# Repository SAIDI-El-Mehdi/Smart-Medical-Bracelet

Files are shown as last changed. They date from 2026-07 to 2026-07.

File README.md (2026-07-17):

# Smart Medical Bracelet (IoT Health Monitor) 🩺⌚

An integrated mechatronics and IoT project focused on designing a wearable medical bracelet for continuous health monitoring. This project encompasses the full product development lifecycle, from system modeling to hardware design and mobile application deployment.

<p align="center">
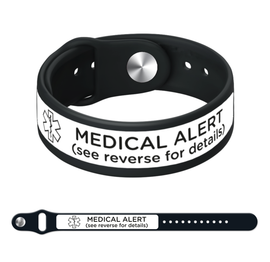
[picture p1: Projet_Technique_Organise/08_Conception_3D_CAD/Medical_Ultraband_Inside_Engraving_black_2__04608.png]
Smart Medical Bracelet Render
  
</p>

---

## 🚀 Key Engineering Dimensions

*   **Systems Engineering (SysML):** Comprehensive system architecture modeling (Requirements, Block Definition, and State Machine diagrams) to define functional relationships and data flow.
*   **Hardware Architecture (PCB Design - Eagle):** Custom printed circuit board design integrating vital sign sensors, power management, and wireless communication modules (IoT/Bluetooth).
*   **Mechanical & CAD Design (3D CAD):** Ergonomic and durable wearable casing designed for comfort, optimal sensor placement against the skin, and manufacturability.
*   **Software & Connectivity (Mobile App):** A dedicated companion mobile application developed to receive, process, and display real-time telemetry data from the bracelet.

---

## 📂 Repository Structure

The project is highly organized into the following engineering phases:

```text
Projet_Technique_Organise/
├── 01_Rapport/                  # Comprehensive project documentation and thesis reports
├── 02_Presentation/             # Slide decks and technical defense materials
├── 03_Code_Source/              # Firmware for the embedded microcontroller
├── 04_Simulation/               # System and physical simulations
├── 05_PCB_Eagle/                # PCB schematics and board layouts (Autodesk Eagle)
├── 06_Documentation/            # Datasheets and component references
├── 08_Conception_3D_CAD/        # Mechanical enclosure models and CAD assemblies
├── 09_Modelisation_SysML/       # System modeling diagrams (MBSE)
└── 10_Application_Mobile/       # Source code for the companion mobile application

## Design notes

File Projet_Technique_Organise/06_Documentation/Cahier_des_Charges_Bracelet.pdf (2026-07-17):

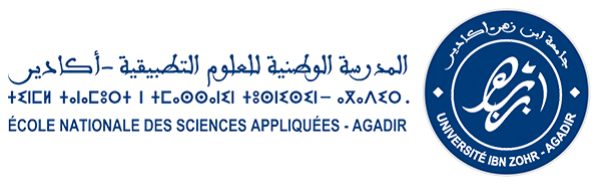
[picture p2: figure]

## École Nationale des Sciences Appliquées d’Agadir

### Université Ibn Zohr

### Filière : Mécatronique et technologies automobiles

### Module : Projet Technique

# Cahier des charges

# Bracelet de surveillance du rythme cardiaque et détection de chute

Membres du groupe

Hamid El-Ghardaouy
Hajar Ziki
Wael El Garrab

Encadrants

Pr. O. Outamsaa
Pr. R. Latif
Pr. M. Bouasrya

### Année universitaire 2025–2026

Cahier des charges – Bracelet de surveillance | ENSA Agadir

## Résumé

Ce cahier des charges définit les besoins, les fonctions, les contraintes, les exigences techniques et les critères de validation du projet de bracelet de surveillance du rythme cardiaque et de détection de chute. Le système visé est un prototype académique portable destiné à représenter ou acquérir une information cardiaque, exploiter des données de mouvement, détecter une situation anormale et déclencher une alerte locale.

Le bracelet repose sur une architecture mécatronique associant un boîtier mécanique, une carte électronique d’interconnexion, un microcontrôleur ESP32-C3 Super Mini, un capteur cardiaque MAX30102, un capteur inertiel MPU6050, un buzzer, un bouton d’acquittement, un interrupteur marche/arrêt et une alimentation par batterie. La logique embarquée est étudiée par simulation afin de vérifier la lecture des données, la comparaison avec des seuils expérimentaux, la détection d’anomalie et l’activation de l’alerte. Une application mobile prototype complète l’étude en affichant des valeurs simulées, des alertes, des courbes, un historique et un contact d’urgence.

Le projet ne constitue pas un dispositif médical certifié. Il est défini comme une base technique d’étude, de simulation, d’intégration et de validation progressive. Les essais matériels réels, l’ajustement expérimental des seuils, la validation des capteurs physiques, l’autonomie, la robustesse mécanique et la communication réelle avec l’application mobile restent des étapes à finaliser avant toute conclusion sur le fonctionnement réel du bracelet.

Page 1 sur 22

## Table des matières

1 Introduction | 5
2 Présentation générale du projet | 5
3 Problématique | 6
4 Objectifs du projet | 7
5 Analyse du besoin | 8
6 Fonctions principales | 9
7 Fonctions contraintes | 10
8 Architecture fonctionnelle et technique | 11

Page 2 sur 22

9 Exigences techniques générales | 12
10 Exigences mécaniques | 13
11 Exigences électroniques | 14
12 Exigences embarquées | 15
13 Application mobile prototype | 17

Page 3 sur 22

14 Analyse de risque et apprentissage automatique | 18
15 Contraintes de sécurité | 18
16 Critères de validation | 18
17 Limites du projet | 19
18 Livrables attendus | 20
19 Planning prévisionnel | 21
20 Conclusion | 22

Page 4 sur 22

## 1 Introduction

Les systèmes embarqués portables occupent une place importante dans les applications modernes de surveillance, d’assistance et de suivi en temps réel. Un bracelet intelligent présente un intérêt particulier, car il est proche du corps, accessible, léger et adapté à une utilisation quotidienne. Cette proximité permet de placer un capteur cardiaque contre la peau et de suivre le mouvement du porteur à l’aide d’une unité inertielle.

Le problème étudié concerne la surveillance locale d’un utilisateur à partir de deux infor-mations complémentaires : une information physiologique liée au rythme cardiaque et une information dynamique liée à l’accélération et au mouvement du corps. Une variation anormale du rythme cardiaque ou une chute peut nécessiter une alerte rapide, au minimum sous forme sonore, puis éventuellement sous forme de notification ou de message préparé dans une application mobile.

La motivation du projet est de concevoir une chaîne mécatronique complète : intégration mécanique, conception électronique, routage PCB, acquisition de données, traitement embarqué, alerte locale et préparation d’une extension mobile. Le présent cahier des charges fixe le cadre technique du projet afin de guider la conception, limiter les ambiguïtés entre les sous-systèmes et préparer une validation progressive.

## 2 Présentation générale du projet

### 2.1 Idée générale

Le projet consiste à concevoir un bracelet portable de surveillance capable de remplir trois fonctions essentielles : surveiller une information liée au rythme cardiaque, détecter une chute ou un impact à partir d’un capteur inertiel et déclencher une alerte en cas d’anomalie. Le système doit rester compact, compréhensible, modifiable et compatible avec un travail académique de conception, de simulation et de validation progressive.

### 2.2 Rôle de la partie mécanique

La partie mécanique assure l’intégration physique du bracelet. Elle comprend le boîtier, le couvercle, les ouvertures fonctionnelles, les supports internes, les zones d’accès utilisateur et les réservations destinées au PCB, à la batterie, aux capteurs et aux actionneurs. Elle doit protéger les composants, permettre le port au poignet, faciliter le montage et éviter les contraintes excessives sur les éléments sensibles, notamment la batterie et les fils.

Page 5 sur 22

### 2.3 Rôle de la partie électronique

La partie électronique organise les liaisons entre le microcontrôleur, les capteurs, l’alimentation et les éléments d’alerte. Le PCB étudié joue principalement le rôle d’une carte d’interconnexion centrée sur l’ESP32-C3 Super Mini. Les modules externes, notamment le MAX30102, le MPU6050, le buzzer, le bouton, l’interrupteur et l’entrée d’alimentation, sont raccordés par connecteurs et fils afin de faciliter leur positionnement dans le boîtier.

### 2.4 Rôle du système embarqué

Le système embarqué réalise l’initialisation, l’acquisition, le traitement et la décision. Il doit lire l’information cardiaque disponible, lire les données d’accélération, calculer des critères simples de chute ou d’impact, comparer les valeurs à des seuils expérimentaux, activer le buzzer lorsque l’alarme est active et permettre un acquittement par bouton.

### 2.5 Rôle de la simulation et de l’application mobile

La simulation sous Wokwi sert à vérifier la logique de fonctionnement avant l’intégration physique. Dans la version étudiée, l’information cardiaque peut être représentée par une entrée analogique simulée, tandis que le MPU6050, le buzzer et le bouton permettent de tester la logique d’alerte. L’application mobile prototype permet de visualiser des valeurs simulées, de conserver un historique, de préparer un message d’urgence et de poser les bases d’une future connexion réelle.

### 2.6 Fonctionnement global attendu

Le fonctionnement attendu peut être résumé par la chaîne suivante :

### Capteurs → Microcontrôleur → Traitement embarqué → Alerte → Interface utilisateur

Au démarrage, le bracelet est alimenté par batterie, initialise le microcontrôleur et configure les entrées, sorties et communications. En fonctionnement normal, il surveille les valeurs disponibles. Si un rythme cardiaque anormal, une chute libre ou un impact est détecté, l’alerte est activée. L’utilisateur peut ensuite acquitter l’alerte selon la logique prévue.

## 3 Problématique

La problématique du projet est formulée ainsi :

Page 6 sur 22

Comment concevoir un système portable de surveillance capable d’intégrer des capteurs, une carte électronique, une logique embarquée et une interface d’alerte, tout en respectant
les contraintes d’un projet académique de conception mécatronique ?

Cette problématique impose une approche pluridisciplinaire. Le système doit être suffisamment compact pour être porté au poignet, suffisamment clair pour être câblé et testé, suffisamment sécurisé pour éviter les erreurs de tension et suffisamment évolutif pour intégrer une validation matérielle et une future communication mobile.

## 4 Objectifs du projet

### 4.1 Objectif principal

L’objectif principal est de concevoir un prototype académique de bracelet portable capable de surveiller une information cardiaque, d’analyser le mouvement du porteur et de déclencher une alerte locale lorsqu’une situation anormale est détectée, tout en servant de base à une validation matérielle future.

### 4.2 Objectifs secondaires

Les objectifs secondaires sont les suivants :

— concevoir un boîtier mécanique portable intégrant les composants principaux ;

— réaliser une étude électronique autour de l’ESP32-C3 Super Mini;

— concevoir un PCB d’interconnexion adapté aux modules câblés ;

— prévoir la surveillance du rythme cardiaque avec le MAX30102 ou une représentation simulée pendant la phase Wokwi ;

— exploiter les données du MPU6050 pour étudier la détection de chute ;

— avertir l’utilisateur par une alerte sonore locale ;

— prévoir un acquittement simple par bouton poussoir ;

— respecter les niveaux d’alimentation, la masse commune et la compatibilité logique 3,3 V ;

— vérifier la logique de fonctionnement par simulation embarquée ;

— préparer une application mobile prototype pour l’affichage, l’historique et le contact d’urgence ;

Page 7 sur 22

— identifier clairement les limites avant la validation sur prototype réel.

## 5 Analyse du besoin

### 5.1 Utilisateur cible

L’utilisateur cible est une personne portant un bracelet de surveillance dans un contexte expérimental, pédagogique ou académique. Le système peut servir à illustrer une solution d’assistance locale, de suivi simple et d’alerte, sans remplacer un suivi médical réel.

### 5.2 Contexte d’utilisation

Le bracelet est destiné à être porté au poignet dans un environnement d’étude, de démonstration ou de test. L’utilisation prévue concerne principalement la validation du principe de fonctionnement : acquisition ou représentation des mesures, traitement et alerte. Les conditions réelles d’usage prolongé, de transpiration, de mouvement complexe, de choc mécanique ou d’autonomie complète doivent encore être évaluées sur prototype physique.

### 5.3 Besoin principal

Le besoin principal est de disposer d’un objet portable académique capable de surveiller une information liée au rythme cardiaque, d’exploiter les données d’un capteur inertiel pour détecter une chute, de déclencher une alerte locale et de préparer une extension mobile. Le système doit rester une base d’étude et de validation progressive, sans prétendre constituer un dispositif médical certifié.

### 5.4 Besoins secondaires

Les besoins secondaires concernent l’ergonomie, la maintenance, l’accès aux composants, la clarté du câblage, la stabilité mécanique des capteurs, la sécurité électrique, l’évolutivité du code embarqué, la documentation des résultats et la préparation d’essais réels futurs.

### 5.5 Contraintes d’usage

Le bracelet doit être compact, léger, non agressif pour le poignet et simple à manipuler. Les éléments accessibles, comme le bouton et l’interrupteur, doivent être positionnés de manière à éviter les appuis accidentels tout en restant utilisables. Le capteur cardiaque

Page 8 sur 22 doit être orienté vers la peau et le buzzer doit disposer d’une sortie sonore suffisante pour rendre l’alerte identifiable dans un contexte de démonstration.

### 5.6 Limites du prototype

Le prototype actuel reste une étude académique. Les données de simulation ne représentent pas toutes les conditions réelles. Le comportement du capteur cardiaque dépendra du contact avec la peau, de la lumière parasite, du mouvement et du placement mécanique. La détection de chute dépendra de la fixation du MPU6050, des seuils choisis et du scénario réel de chute.

## 6 Fonctions principales

Table 1: Fonctions principales du bracelet.

Code Fonction | Description | Critère attendu Priorité Validation
FP1 | Surveiller une
information cardiaque | Acquérir ou représenter une valeur de BPM dans le cadre du prototype. | Valeur BPM disponible, réelle ou simulée.
Élevée | Simulation
| | puis test MAX30102 réel.
FP2 | Détecter une chute Exploiter les accélérations
| du MPU6050 pour détecter une chute libre, un impact ou un mouvement anormal. | État de chute
| | ou d’impact identifié.
Élevée | Wokwi puis
| | scénarios réels.
FP3 | Déclencher une
alerte locale

Activer un buzzer
lorsqu’une anomalie
cardiaque ou une chute est détectée.

Buzzer actif
pendant
l’alarme.

Élevée Simulation
puis test
matériel.

FP4 Permettre
l’acquittement

Permettre à l’utilisateur
d’arrêter ou de confirmer
l’alerte par bouton.

Changement
d’état reconnu
par le
programme.

Élevée Simulation
puis test du
bouton.

FP5 Afficher ou
préparer les
données

Préparer l’affichage des
valeurs, alertes, courbes, historique et contact dans une application prototype.

Interface
mobile lisible
avec données
simulées.

Moyenne Test logiciel de
l’application.

FP6 Intégrer les
composants

Placer le PCB, les capteurs, la batterie, le buzzer, le bouton et l’interrupteur
dans un boîtier portable.

Composants
positionnés
sans conflit
après
adaptation.

Élevée Étude CAO
puis
assemblage
réel.

Page 9 sur 22

## 7 Fonctions contraintes

Table 2: Fonctions contraintes du projet.

Code Contrainte | Description | Priorité | Vérification
FC1 | Portabilité | Le système doit conserver un
| encombrement compatible avec un port au poignet. | Élevée | Étude CAO.
FC2 | Confort au poignet Les arêtes doivent être adoucies et
la zone en contact avec la peau ne doit pas être agressive.

Élevée Revue CAO
puis essai réel.

FC3 Sécurité électrique Les rails doivent être clairement identifiés et les GPIO protégés contre une tension incorrecte.

Élevée ERC, DRC,
inspection.
FC4 | Compatibilité des tensions | Le 5 V ne doit jamais être appliqué directement aux GPIO de l’ESP32-C3.
Élevée | Contrôle des
nets.
FC5 | Alimentation par batterie | L’alimentation doit être compatible avec les modules et la masse commune.
Élevée | Mesures
futures.
FC6 | Intégration du PCB La carte doit être compatible avec le
| | boîtier ou le boîtier doit être adapté.
Élevée | Comparaison
CAO/PCB.
FC7 | Position du capteur cardiaque | Le MAX30102 doit être orienté vers la peau et aligné avec son ouverture.
Élevée | Vue CAO puis
essai réel.
FC8 | Fixation du capteur inertiel | Le MPU6050 doit être fixé de manière stable.
Élevée | Contrôle
mécanique
futur.
FC9 | Masse commune | Tous les blocs doivent partager une référence GND commune.
Élevée | Inspection
schéma/PCB.
FC10 Accessibilité du
| bouton | Le bouton doit être accessible sans appui involontaire.
Moyenne | Vue CAO puis
essai
utilisateur.
FC11 Accessibilité de
| l’interrupteur | L’interrupteur marche/arrêt doit être manipulable.
Moyenne | Vue CAO puis
essai réel.
FC12 Sortie sonore du
| buzzer | Le boîtier doit permettre la sortie du son.
Moyenne | Ouverture
CAO puis test
sonore.
FC13 Limites de
| simulation | Les résultats simulés ne doivent pas être assimilés à des tests réels.
Élevée | Mention dans
le rapport.
FC14 Coût raisonnable | Les composants doivent rester
| | compatibles avec un projet académique.
Moyenne | Choix de
modules
courants.

Page 10 sur 22

Code Contrainte | Description | Priorité | Vérification
FC15 Simplicité de réalisation | Le système doit rester compréhensible, câblable et modifiable. | Élevée | Revue
| | | d’architecture.

## 8 Architecture fonctionnelle et technique

### 8.1 Architecture globale

L’architecture du bracelet suit une chaîne de traitement simple et modulaire :

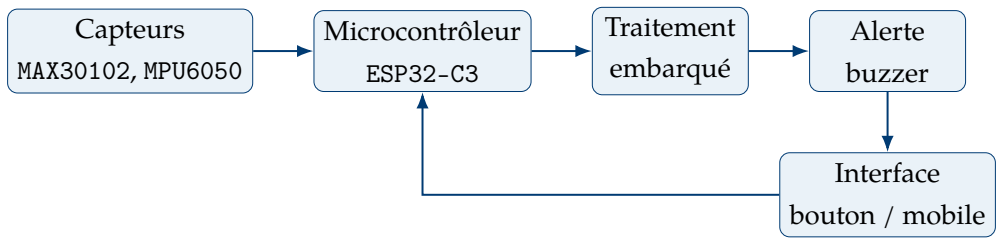
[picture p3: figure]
Capteurs; MAX30102, MPU6050; Microcontrôleur; ESP32-C3; Traitement embarqué; Alerte; buzzer; Interface; bouton / mobile

### 8.2 Blocs du système

— Boîtier mécanique : supporte, protège et positionne les composants.

— Microcontrôleur : l’ESP32-C3 Super Mini assure l’acquisition, le traitement et la commande.

— Capteur cardiaque : le MAX30102 est prévu pour fournir une information liée au rythme cardiaque lors d’une validation matérielle.

— Capteur inertiel : le MPU6050 fournit les accélérations utilisées pour la détection de chute.

— Alerte locale : le buzzer informe l’utilisateur lorsqu’une alarme est active.

— Interface utilisateur : le bouton permet l’acquittement ou le test ; l’interrupteur contrôle l’alimentation.

— Alimentation : batterie Li-Po et entrée d’alimentation prévues, avec masse commune et niveaux compatibles.

— Application mobile prototype : affiche les valeurs simulées, les alertes, l’historique, les courbes et le contact d’urgence.

Page 11 sur 22

### 8.3 Flux principaux

— Flux d’information : capteurs vers microcontrôleur, puis microcontrôleur vers sortie d’alerte et application prototype.

— Flux d’énergie : batterie ou entrée d’alimentation vers microcontrôleur, capteurs et buzzer.

— Flux de commande : décision embarquée vers buzzer, puis acquittement par bouton vers microcontrôleur.

## 9 Exigences techniques générales

Table 3: Exigences techniques principales.

Code Exigence | Justification | Critère de validation

État

ET1 Utiliser un ESP32-C3 Super Mini.
Format compact,
traitement embarqué et
évolution connectée.

Présence dans le
schéma et
initialisation du
programme.

Étudié

ET2 Prévoir le capteur MAX30102.

Surveillance cardiaque
future.

Lecture réelle à
valider ; BPM
simulé en Wokwi.

Partiel

ET3 | Utiliser le capteur MPU6050. | Détection de chute à partir des accélérations.
Reconnaissance I2C
et lecture des axes.

Simulé

ET4 | Identifier SDA et SCL. | Communication I2C entre capteurs et microcontrôleur.
Continuité des
lignes et masse
commune.

Étudié

ET5 Commander un buzzer. Alerte locale simple et visible dans le comportement du système.

Activation lorsque
l’alarme est active.

Simulé

ET6 Prévoir un bouton d’acquittement.

Interaction utilisateur
simple.

Changement d’état
détecté par le
programme.

Simulé

ET7 Prévoir une alimentation par batterie et entrée dédiée.

Fonctionnement portable
et tests futurs.

Tension correcte et
polarité vérifiée.

À valider

ET8 Garantir les niveaux 3,3 V sur les GPIO.

Protection de l’ESP32-C3. Aucun 5 V direct sur GPIO.

À vérifier

Page 12 sur 22

Code Exigence | Justification | Critère de validation

État

ET9 Concevoir un PCB d’interconnexion.

Faciliter le câblage et
l’intégration.

ERC, DRC et
inspection des
connecteurs.

Étudié

ET10 Vérifier les dimensions PCB/support.

Éviter les conflits
mécaniques.

Comparaison PCB
42,85 × 38,09 mm
et support 36,50 ×
29,50 mm.

À ajuster

ET11 Simuler la logique sous Wokwi.

Valider le fonctionnement
avant prototype réel.

Cas d’alerte
visibles au
moniteur série et
au Serial Plotter.

Réalisé

ET12 Préparer une application mobile prototype.

Visualisation et extension connectée future.

Écrans, historique,
notifications et
contact testés avec
données simulées.

Prototype

ET13 Limiter l’interprétation médicale.

Éviter toute conclusion
abusive.

Mention claire
dans le cahier des
charges et le
rapport.

Respecté

## 10 Exigences mécaniques

### 10.1 Forme du boîtier

Le boîtier doit adopter une forme compacte, arrondie et compatible avec un port au poignet. Les arêtes agressives doivent être évitées. Le couvercle doit permettre l’accès interne pour les tests, la maintenance et les ajustements.

### 10.2 Intégration du PCB

Le PCB doit être maintenu dans le boîtier sans contact dangereux avec la batterie ou les fils. L’étude actuelle montre une différence entre les dimensions du PCB et celles du support interne prévu. Cette différence impose soit un redimensionnement du support, soit une adaptation de la carte avant fabrication.

Page 13 sur 22

### 10.3 Position du capteur cardiaque

Le MAX30102 doit être placé de manière à aligner sa zone optique avec une ouverture orientée vers la peau. L’ouverture doit rester dégagée afin de ne pas masquer la zone active du capteur.

### 10.4 Position du capteur inertiel

Le MPU6050 doit être fixé de façon stable pour limiter les vibrations parasites. Son placement doit éviter les mouvements relatifs entre le module et le boîtier, car ces mouvements peuvent perturber la détection de chute.

### 10.5 Bouton, interrupteur et buzzer

Le bouton poussoir doit être accessible sans risque d’appui involontaire. L’interrupteur marche/arrêt doit être placé sur une zone manipulable. Le buzzer doit disposer d’une ouverture ou d’une zone de sortie sonore afin que l’alerte reste audible.

### 10.6 Protection et assemblage

Le boîtier doit protéger les modules contre les contacts directs, les contraintes mécaniques et les courts-circuits. La batterie Li-Po doit être maintenue sans compression excessive. Les fils doivent passer dans des zones dégagées, sans pincement par le couvercle.

## 11 Exigences électroniques

### 11.1 Microcontrôleur

L’ESP32-C3 Super Mini est l’unité centrale du système. Il assure l’acquisition des données, le traitement logique, l’activation de l’alerte et la préparation d’une future communication avec l’application mobile.

### 11.2 Capteurs

Le MAX30102 est prévu pour assurer la fonction de surveillance cardiaque lors d’une validation matérielle. Le MPU6050 assure la mesure inertielle pour l’étude de la détection de chute. Les deux modules doivent être raccordés avec des lignes SDA, SCL, VCC et GND clairement identifiées.

Page 14 sur 22

### 11.3 Alimentation

Le système doit disposer d’une alimentation adaptée au microcontrôleur et aux modules. La masse commune est obligatoire. La présence d’un rail 5 V doit être traitée avec prudence : il peut servir d’entrée d’alimentation selon l’architecture retenue, mais il ne doit jamais être appliqué directement aux GPIO de l’ESP32-C3.

### 11.4 Entrées et sorties

Le buzzer doit être raccordé à une sortie compatible avec le courant admissible. Si le buzzer exige un courant supérieur à la capacité d’une broche GPIO, un étage de commande devra être ajouté dans une version améliorée. Le bouton poussoir doit disposer d’un état logique stable, par résistance de tirage interne ou externe. La LED prévue dans le schéma électronique peut servir d’indicateur visuel, mais elle n’est pas considérée comme validée dans la simulation actuelle si elle n’est pas commandée par le programme.

### 11.5 Règles de câblage et de routage

Les règles de câblage importantes sont les suivantes :

— identifier clairement les rails 3V3, 5V et GND;

— éviter toute connexion directe du 5V sur les GPIO ;

— garder une masse commune entre tous les modules ;

— contrôler les lignes SDA et SCL;

— vérifier les connecteurs avant fabrication ;

— exécuter l’ERC pour vérifier la cohérence du schéma ;

— exécuter le DRC pour vérifier les règles géométriques du routage ;

— contrôler les largeurs de pistes d’alimentation ;

— vérifier la continuité du bouton, du buzzer, de la LED et de l’interrupteur.

## 12 Exigences embarquées

Page 15 sur 22

### 12.1 Initialisation du système

Le programme doit initialiser la communication série, configurer les broches d’entrée et de sortie, initialiser le bus I2C et vérifier la présence du MPU6050. L’alarme doit être inactive au démarrage.

### 12.2 Acquisition des données

Le système doit acquérir une information liée au rythme cardiaque et lire les accélérations selon les axes du MPU6050. Dans la simulation Wokwi actuelle, le rythme cardiaque est représenté par une entrée analogique convertie en BPM.

### 12.3 Traitement des mesures

Le traitement doit calculer une grandeur exploitable à partir des accélérations, notamment la norme d’accélération. Les seuils de rythme cardiaque et d’accélération sont des paramètres de simulation et doivent être ajustés après essais réels.

### 12.4 Détection d’anomalie cardiaque

Une anomalie cardiaque est détectée si le BPM sort de la plage définie par les seuils bas et haut. Les seuils utilisés dans la version prototype servent à vérifier la logique et ne constituent pas une recommandation médicale.

### 12.5 Détection de chute

La détection de chute repose sur deux cas simples : une accélération inférieure à un seuil de chute libre ou une accélération supérieure à un seuil d’impact. Cette logique doit être validée expérimentalement, car les conditions réelles dépendent du mouvement, de la fixation du capteur et du port du bracelet.

### 12.6 Activation et acquittement de l’alerte

L’alerte est activée lorsqu’une anomalie cardiaque ou une chute est détectée. Le buzzer est activé tant que l’alarme reste active. Le bouton poussoir doit permettre l’acquittement de l’alerte selon la logique prévue.

Page 16 sur 22

### 12.7 Validation par simulation

La simulation doit permettre d’observer les variables principales : BPM, accélération, présence du MPU6050, anomalie cardiaque, chute, acquittement et état de l’alarme. Les résultats obtenus en simulation ne remplacent pas les tests sur prototype réel.

## 13 Application mobile prototype

### 13.1 Objectif de l’application

L’application mobile constitue une extension prototype du bracelet. Elle ne reçoit pas encore de données réelles du bracelet dans la version actuelle. Elle permet de valider l’interface, l’affichage, l’historique, les alertes et le contact d’urgence à partir de données simulées.

### 13.2 Fonctions attendues

L’application mobile prototype doit permettre :

— l’affichage du BPM simulé ;

— l’affichage de l’état de chute ou de mouvement anormal ;

— l’affichage d’un état général : normal, danger ou déconnecté ;

— la conservation d’un historique d’alertes ;

— l’affichage de courbes simples ;

— l’enregistrement d’un contact d’urgence ;

— la préparation d’un message SOS contrôlé par l’utilisateur;

— la préparation d’une future communication BLE avec l’ESP32-C3.

### 13.3 Limites de l’application

L’application ne remplace pas un système médical ni un service d’urgence certifié. Les données affichées sont simulées dans la version actuelle. La communication BLE, la réception de données réelles, la gestion robuste du stockage et les tests prolongés restent des évolutions futures.

Page 17 sur 22

## 14 Analyse de risque et apprentissage automatique

Une analyse de risque avancée ou une approche par apprentissage automatique peut être envisagée comme perspective. Elle ne fait pas partie de la validation actuelle du bracelet. Une telle évolution nécessiterait :

— une collecte de données réelles ;

— un étiquetage fiable des scénarios ;

— un nettoyage des données ;

— une extraction de caractéristiques pertinentes ;

— un entraînement du modèle ;

— une validation sur des données séparées ;

— une analyse des fausses alertes et des non-détections.

Sans base de données suffisante et sans validation expérimentale rigoureuse, aucun modèle ne peut garantir une prédiction fiable ni une interprétation médicale.

## 15 Contraintes de sécurité

— éviter les tensions incorrectes sur les broches du microcontrôleur ;

— éviter les courts-circuits entre l’alimentation et la masse ;

— isoler correctement les parties conductrices du contact utilisateur ;

— maintenir la batterie sans compression, perforation ou échauffement anormal ;

— vérifier la polarité de l’alimentation avant toute mise sous tension ;

— éviter les fausses alertes autant que possible par un réglage progressif des seuils ;

— distinguer clairement les résultats simulés des résultats expérimentaux réels ;

— préciser que le système n’est pas un dispositif médical certifié.

## 16 Critères de validation

Page 18 sur 22

Table 4: Critères de validation du prototype académique.

Critère | Méthode de vérification | Résultat attendu | État
Validation mécanique | Revue CAO, comparaison des volumes, contrôle des ouvertures et supports. | Boîtier cohérent avec les composants prévus. | Réalisée au niveau CAO
Intégration PCB/boîtier | Comparaison dimensions PCB, support interne et zones de câblage. | Adaptation identifiée avant fabrication. | À ajuster

Alimentation
correcte

Mesure future des rails et contrôle de polarité.

Tensions compatibles avec
l’ESP32-C3 et les modules.

À valider
matériellement
Vérification schéma ERC sous EAGLE et inspection des nets critiques.

Absence d’erreurs critiques du schéma.

Prévue / à
documenter
Vérification routage DRC sous EAGLE et inspection des distances.

Absence d’erreurs critiques de routage.

Prévue / à
documenter
Lecture cardiaque Test du MAX30102 réel ou représentation analogique en simulation.

Valeur BPM disponible ou
simulée.

Simulée / à
valider réel

Lecture inertielle Lecture I2C du MPU6050 et calcul de la norme d’accélération.

Axes lus et norme calculée. Simulée

Activation buzzer Déclenchement d’une alarme en simulation puis test réel.

Buzzer actif en cas
d’alarme.

Simulée / à
confirmer
Acquittement bouton | Appui sur le bouton et lecture de l’entrée.
Désactivation ou
confirmation de l’alarme.

Simulé / à
confirmer
Simulation Wokwi Observation du moniteur série et du Serial Plotter.

États d’alerte cohérents
selon les scénarios.

Réalisée

Code embarqué Lecture du code, compilation et observation de la logique.

Initialisation, lecture,
traitement et alerte
cohérents.

Simulé

Application mobile Test des écrans, historique, notifications et contact SOS préparé.

Interface fonctionnelle avec données simulées.

Prototype réalisé

Communication BLE Test de liaison ESP32-C3 vers application mobile.

Données réelles reçues par l’application.

À réaliser

Validation finale Tests complets sur bracelet assemblé. Fonctionnement global
confirmé sur prototype
physique.

À réaliser

## 17 Limites du projet

Les limites du projet doivent être définies clairement afin d’éviter toute conclusion excessive :

Page 19 sur 22

— le bracelet est un prototype académique ;

— le système n’est pas un dispositif médical certifié ;

— les seuils utilisés servent à tester la logique d’alerte et doivent être ajustés expérimentalement ;

— les données de l’application mobile sont simulées dans la version actuelle ;

— la communication BLE réelle avec le bracelet n’est pas encore intégrée ;

— la validation des capteurs physiques reste nécessaire ;

— l’intégration mécanique réelle n’est pas encore confirmée par assemblage ;

— l’autonomie énergétique n’est pas validée tant qu’aucune mesure de consommation n’est réalisée ;

— la robustesse mécanique n’est pas validée tant que le boîtier n’est pas imprimé et testé ;

— les dimensions du support PCB doivent être adaptées à la carte étudiée ;

— les fausses alertes et les non-détections doivent être étudiées sur des scénarios réels ;

— une éventuelle analyse de risque avancée nécessiterait des données réelles, un étiquetage et une validation rigoureuse.

## 18 Livrables attendus

Table 5: Livrables du projet.

Livrable | Description | État attendu
Cahier des charges | Besoin, fonctions, contraintes, exigences, validation et limites. | Réalisé
Modèle SolidWorks | Boîtier, couvercle, ouvertures et zones d’intégration. | Réalisé au niveau CAO
Étude d’intégration | Comparaison entre PCB, modules et
| boîtier. | À ajuster avant
| | fabrication
Schéma électronique | Schéma sous EAGLE avec composants et connecteurs. | Réalisé au niveau étude
Routage PCB | Carte d’interconnexion centrée sur l’ESP32-C3. | Réalisé au niveau étude
Simulation embarquée | Wokwi, ESP32-C3, MPU6050, BPM simulé, buzzer et bouton. | Réalisée
Code embarqué | Code Arduino/C utilisé pour la simulation. | Réalisé pour simulation
| Page 20 sur 22

Livrable | Description | État attendu

Application mobile prototype Interface Flutter avec valeurs
| simulées, alertes, historique, courbes et contact. | Prototype réalisé
Captures de validation | Captures SolidWorks, EAGLE, Wokwi et application mobile.

À intégrer au rapport

Rapport technique | Document final décrivant les choix, résultats et limites.

À finaliser

Présentation orale | Synthèse du projet, démonstration et perspectives.

Prévue si demandée

Corrections futures | Liste des ajustements avant prototype physique.

À compléter

## 19 Planning prévisionnel

Le planning prévisionnel présente l’organisation du projet sur une durée totale de quatre semaines. Il distingue les travaux d’étude, les simulations effectuées et les étapes qui restent à valider sur matériel réel. Le projet n’est donc pas présenté comme un prototype physique finalisé, mais comme une étude mécatronique complétée par une simulation embarquée et une application mobile prototype.

Table 6: Planning prévisionnel du projet sur quatre semaines.

Semaine | Tâche principale | Durée | Livrable associé | État

Semaine 1 Cadrage du besoin, analyse

| fonctionnelle, identification des fonctions principales et contraintes. | 1 semaine | Cahier des charges synthétisé et fonctions du système. | Étudié

Semaine
1–2

Étude mécanique du bracelet : boîtier, couvercle, ouvertures, ergonomie et zones
d’intégration.

2 semaines Modèle SolidWorks, vues mécaniques et captures du boîtier.

Étudié

Semaine 2 Étude d’intégration mécanique : positionnement du PCB,
capteurs câblés, bouton, buzzer, interrupteur et batterie.

1 semaine Dimensions d’intégration, supports internes et contraintes d’encombrement.

À ajuster

Semaine
2–3

Étude électronique : schéma du système, connecteurs,
alimentation, bus I2C et signaux principaux.

2 semaines Schéma électronique sous EAGLE.

Étudié

Page 21 sur 22

Semaine | Tâche principale | Durée | Livrable associé | État

Semaine 3 Routage numérique du PCB

| autour de l’ESP32-C3 et organisation des connecteurs. | 1 semaine | Vue PCB, routage, dimensions de la carte et captures EAGLE. | Étudié

Semaine 4 Simulation embarquée sous Wokwi : logique de détection, BPM simulé, MPU6050, buzzer et acquittement.

1 semaine Schéma Wokwi, code Arduino/C, moniteur série et captures de simulation. Simulé

Semaine 4 Développement du prototype d’application mobile sous
Flutter avec données simulées.

1 semaine Interface mobile, tableau de bord, alertes, historique, courbes et score expérimental. Prototype

Semaine 4 Documentation technique et synthèse des résultats étudiés ou simulés.

1 semaine Rapport technique du projet. En cours

Après les 4
semaines

Assemblage matériel, tests réels, communication BLE, ajustement des seuils et validation
expérimentale.

Étape future Prototype physique validé
expérimentalement.

À réaliser

## 20 Conclusion

Ce cahier des charges définit le cadre fonctionnel et technique du bracelet de surveillance du rythme cardiaque et de détection de chute. Le besoin principal consiste à concevoir un système portable académique capable de surveiller une information cardiaque, d’analyser le mouvement du porteur et de déclencher une alerte locale en cas d’anomalie.

Les fonctions principales concernent la surveillance du rythme cardiaque, la détection de chute, l’alerte locale, l’acquittement, l’intégration dans un boîtier portable et la préparation d’une application mobile prototype. Les contraintes majeures concernent la compacité, le confort au poignet, la compatibilité des tensions, la masse commune, la sécurité électrique, l’accessibilité des éléments, la clarté du câblage et l’adaptation entre la carte PCB et le boîtier.

Le projet possède un intérêt mécatronique fort, car il associe conception mécanique, conception électronique, routage PCB, simulation embarquée et application mobile prototype. La suite du travail devra porter sur l’adaptation dimensionnelle, l’assemblage physique, la validation des capteurs réels, l’ajustement des seuils, la vérification de l’alimentation, la mesure de l’autonomie et l’intégration de la communication réelle avec l’application mobile. Le système doit rester présenté comme un prototype académique de surveillance et d’alerte, sans certification médicale.

Page 22 sur 22

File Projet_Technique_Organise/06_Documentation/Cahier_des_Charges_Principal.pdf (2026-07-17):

## Cahier des charges synthétique

Bracelet de surveillance du rythme cardiaque et détection de chute
École Nationale des Sciences Appliquées d’Agadir – Université Ibn Zohr Filière : Mécatronique et technologies automobiles Membres du groupe : Hamid El-Ghardaouy, Hajar Ziki, Wael El Garrab Année universitaire 2025–2026

### 1. Contexte et besoin

Le projet porte sur la conception d’un bracelet portable de surveillance et d’alerte. Il vise à exploiter une information liée au rythme cardiaque et des données de mouvement afin d’identifier une situation anormale. L’utilisateur cible est une personne portant le bracelet dans un contexte expérimental, pédagogique ou de démonstration. Le besoin principal est de disposer d’un prototype académique compact, testable et évolutif, sans remplacer un suivi médical réel.

### 2. Problématique

La problématique consiste à concevoir un système portable capable d’intégrer des capteurs, une carte d’interconnexion, une alimentation, une logique embarquée, une alerte locale et une application mobile prototype. Le système doit rester compatible avec les contraintes mécaniques, électroniques et de validation d’un projet mécatronique académique.

### 3. Objectif principal et objectifs secondaires

L’objectif principal est de concevoir un prototype de bracelet capable de surveiller une information cardiaque, d’analyser le mouvement du porteur et de déclencher une alerte locale en cas d’anomalie, tout en servant de base à une validation matérielle future. Les objectifs secondaires sont :
— intégrer le PCB, les capteurs, la batterie, le buzzer, le bouton et l’interrupteur dans un boîtier portable ;
— étudier l’architecture électronique autour de l’ESP32-C3 Super Mini ;
— prévoir le MAX30102 pour l’information cardiaque et le MPU6050 pour la détection de chute ;
— vérifier par simulation la logique d’acquisition, de traitement, d’alerte et d’acquittement ;
— préparer une application mobile prototype avec valeurs simulées, alertes, courbes, historique et contact d’urgence.

### 4. Fonctions attendues

Le bracelet doit assurer cinq fonctions essentielles :
— acquérir ou représenter une valeur liée au rythme cardiaque ;
— exploiter les accélérations du MPU6050 pour détecter une chute libre, un impact ou un mouvement anormal ;
— activer un buzzer lorsqu’une anomalie cardiaque ou une chute est détectée ;
— permettre l’acquittement de l’alerte par bouton poussoir ;
— afficher ou préparer les données dans une application mobile prototype.

### 5. Architecture et besoins techniques

L’architecture suit la chaîne : capteurs, ESP32-C3 Super Mini, traitement embarqué, buzzer et interface utilisateur. Le MAX30102 est prévu pour la surveillance cardiaque. Le

MPU6050 fournit les données inertielles. Le bouton assure l’acquittement, l’interrupteur commande la mise sous tension et l’alimentation est prévue par batterie Li-Po avec masse commune.
Le programme embarqué doit initialiser la communication série, les entrées-sorties, le bus I2C et le MPU6050. Il doit lire les données disponibles, calculer une grandeur d’accélération, comparer les valeurs à des seuils de test et commander l’alerte. La simulation Wokwi permet de vérifier la logique avant l’intégration physique. L’application mobile utilise des données simulées et prépare une future communication BLE.

### 6. Contraintes principales

Les contraintes principales sont :
— conserver un encombrement compatible avec un port au poignet et éviter les arêtes agressives ;
— orienter le MAX30102 vers la peau et fixer le MPU6050 de manière stable ;
— garantir la masse commune, identifier SDA, SCL, VCC et GND, et éviter tout 5 V direct sur les GPIO de l’ESP32-C3 ;
— protéger la batterie contre une mauvaise polarité, une compression excessive, un échauffement anormal et tout risque de court-circuit ;
— contrôler le schéma par ERC et le routage par DRC ;
— adapter l’intégration entre le PCB étudié de 42,85 mm × 38,09 mm et le support interne prévu de 36,50 mm × 29,50 mm ;
— distinguer clairement les résultats simulés des essais réels.

### 7. Critères de validation et livrables

Les critères de validation concernent la cohérence mécanique du boîtier, l’intégration PCB/boîtier, la vérification des rails d’alimentation, les contrôles ERC et DRC, la lecture inertielle, l’activation du buzzer, l’acquittement par bouton, la cohérence du code embarqué, les écrans de l’application mobile et la validation future des capteurs réels. Les seuils utilisés servent uniquement à tester la logique d’alerte et ne constituent pas des valeurs médicales.
Les livrables attendus sont le modèle mécanique, l’étude d’intégration, le schéma électronique, le routage PCB, la simulation embarquée, le code de simulation, l’application mobile prototype, les captures de validation et le rapport technique.

### 8. Limites du projet

Le bracelet reste un prototype académique. Les données de simulation ne remplacent pas les essais réels. La validation des capteurs physiques, l’ajustement expérimental des seuils, l’étude des fausses alertes et des non-détections, l’autonomie, la robustesse mécanique, l’assemblage complet et la communication réelle avec l’application mobile restent à vérifier. Le système ne doit pas être présenté comme un dispositif médical, industriel ou certifié.

### 9. Conclusion

Ce document fixe le cadre fonctionnel et technique minimal du bracelet. Il définit le besoin, les fonctions, l’architecture, les contraintes, les critères de validation, les livrables et les limites du prototype. La suite du travail doit porter sur l’adaptation dimensionnelle, l’assemblage physique, les essais expérimentaux et la communication réelle, sans conclure prématurément sur un fonctionnement certifié.

2

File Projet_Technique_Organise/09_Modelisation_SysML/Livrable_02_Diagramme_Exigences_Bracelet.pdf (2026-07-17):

Cameo Systems Modeler, 1-1 D:\S4 MTA\B- Projet Technique\SysML\Bracelet_Surveillance_Cardiaque_Detection_Chute.mdzip Diagramme_Exigences May 9, 2026 5:18:00 PM

req [Package] RD_Architecture_Fonctionnelle_Bracelet Diagramme_Exigences [ | ]

Text = "Le système Bracelet de surveillance doit
surveiller une information cardiaque, exploiter des
données de mouvement,
détecter une situation
anormale et déclencher une alerte locale dans le cadre d’ un prototype académique
portable."

Id = "1"

REQ-00 Systeme Bracelet

«requirement»

Text = "Le système doit
préparer une application
mobile prototype permettant l’affichage des valeurs
simulées, des alertes, de l’ historique, des courbes et du contact d’urgence."

Id = "1.8"

REQ-08 Application mobile
prototype

«requirement»

Text = "Le système doit
intégrer le PCB, les
capteurs, la batterie, le
buzzer, le bouton et l’
interrupteur dans un boîtier portable compatible avec le port au poignet."

Id = "1.5"

REQ-05 Intégration
mécanique

«requirement»

Text = "Le système doit
acquérir ou représenter une information de rythme
cardiaque afin de disposer d’ une valeur BPM exploitable dans le cadre du prototype."

Id = "1.1"

REQ-01 Surveillance
cardiaque

«requirement»

Text = "Le système doit
permettre d’observer les
variables principales : BPM, accélération, chute,
anomalie cardiaque,
acquittement et état de l’ alarme."

Id = "1.9.2"

Observation variables

«requirement»

Text = "Le système doit
permettre de vérifier la
logique embarquée sous
Wokwi avant les essais
matériels réels."

Id = "1.9.1"

Simulation Wokw i

«requirement»

Affichage valeurs simulées «requirement» | Affichage état alerte «requirement» | «requirement» Historique et courbes | «requirement» Contact urgence
Id = "1.8.1" Text = "Le système doit permettre à l’application mobile prototype d’afficher des valeurs simulées de BPM et d’état de mouvement." | Id = "1.8.2" Text = "Le système doit permettre à l’application mobile prototype d’afficher un état général normal, danger ou déconnecté." | Id = "1.8.3" Text = "Le système doit permettre à l’application mobile prototype de conserver un historique d’ alertes et d’afficher des courbes simples." | Id = "1.8.4" Text = "Le système doit permettre à l’application mobile prototype d’ enregistrer un contact d’ urgence et de préparer un message SOS contrôlé par l’ utilisateur."
«requirement» Alimentation batterie | «requirement» Entrée alimentation dédiée | «requirement» Polarité et tension
Text = "Le système doit Id = "1.7.1" prévoir une alimentation par batterie afin de permettre un fonctionnement portable du bracelet." | Text = "Le système doit Id = "1.7.2" disposer d’une entrée d’ alimentation clairement identifiée pour raccorder l’ énergie au microcontrôleur et aux modules." | Text = "Le système doit Id = "1.7.3" permettre la vérification de la polarité et des tensions d’ alimentation avant toute mise sous tension matérielle."

Text = "Le système doit être vérifié par inspection du
schéma, contrôle des nets
critiques, ERC et DRC avant toute fabrication."

Id = "1.6.4"

Vérification ERC DRC

«requirement»

Text = "Le système doit
relier tous les modules
électroniques à une
référence GND commune."

Id = "1.6.3"

Masse commune

«requirement»

Text = "Le système doit
éviter toute connexion
directe du 5 V sur les
broches GPIO de l’ESP32-
C3."

Id = "1.6.2"

Interdiction 5V GPIO

«requirement»

Text = "Le système doit
garantir que les GPIO de l’
ESP32-C3 fonctionnent
avec des niveaux logiques
compatibles 3,3 V."

Id = "1.6.1"

Compatibilité 3V3

«requirement»

Text = "Le système doit
rendre le bouton poussoir, l’ interrupteur et la sortie
sonore du buzzer
accessibles dans le boîtier."

Id = "1.5.4"

Accessibilité interface

«requirement»

Text = "Le système doit fixer
le MPU6050 de manière
stable afin de limiter les
vibrations parasites pendant la détection de mouvement."

Id = "1.5.3"

Fixation MPU6050

«requirement»

Text = "Le système doit
positionner le capteur
MAX30102 de manière à
orienter sa zone optique
vers la peau."

Id = "1.5.2"

Position capteur cardiaque

«requirement»

Text = "Le système doit
utiliser un boîtier compact,
arrondi et compatible avec un port au poignet."

Id = "1.5.1"

Boîtier portable

«requirement»

Text = "Le système doit
désactiver le buzzer lorsque l’utilisateur acquitte l’alerte selon la logique prévue."

Id = "1.4.2"

Arrêt buzzer

«requirement»

Text = "Le système doit lire l’
état du bouton poussoir afin
de détecter une demande d’ acquittement de l’alerte."

Id = "1.4.1"

Lecture bouton

«requirement»

Text = "Le système doit
maintenir l’alerte active tant que l’anomalie n’est pas
acquittée par l’utilisateur."

Id = "1.3.2"

Maintien alarme

«requirement»

Text = "Le système doit
activer le buzzer lorsque l’
état d’alarme est déclenché par une anomalie cardiaque ou une chute."

Id = "1.3.1"

Activation buzzer

«requirement»

Text = "Le système doit
calculer une grandeur
exploitable à partir des
accélérations afin d’évaluer l’ état dynamique du bracelet."

Id = "1.2.2"

Calcul accélération

«requirement»

Text = "Le système doit
permettre la validation de la logique embarquée par
simulation avant les essais matériels réels."

Id = "1.9"

REQ-09 Validation par
simulation

«requirement»

Text = "Le système doit
prévoir une alimentation par batterie ou entrée dédiée
compatible avec l’ESP32-C3 et les modules utilisés."

Id = "1.7"

REQ-07 Alimentation

«requirement»

Text = "Le système doit
permettre à l’utilisateur d’ acquitter l’alerte à l’aide d’un bouton poussoir."

Id = "1.4"

REQ-04 Acquittement alerte

«requirement»

Text = "Le système doit
activer un buzzer lorsqu’une anomalie cardiaque ou une
chute est détectée."

Id = "1.3"

REQ-03 Alerte locale

«requirement»

Text = "Le système doit
permettre de tester les
scénarios normal, anomalie cardiaque, chute, activation du buzzer et acquittement
de l’alerte."

Id = "1.9.3"

Test scénarios alerte

«requirement»

Text = "Le système doit
distinguer les résultats
simulés des résultats
expérimentaux réels afin d’ éviter toute conclusion
excessive."

Id = "1.9.4"

Limite simulation

«requirement»

Text = "Le système doit
comparer la valeur BPM à
des seuils bas et haut afin de détecter une anomalie
cardiaque dans le cadre de la logique prototype."

Id = "1.1.3"

Seuils cardiaques

«requirement»

Text = "Le système doit
prévoir l’utilisation du
capteur MAX30102 pour la
surveillance cardiaque lors d’ une validation matérielle
future."

Id = "1.1.2"

Capteur MAX30102

«requirement»

Text = "Le système doit
acquérir ou représenter une
valeur BPM afin de disposer d’une information cardiaque exploitable dans le
prototype."

Id = "1.1.1"

Acquisition BPM

«requirement»

Text = "Le système doit
comparer l’accélération à
des seuils de chute libre et d’ impact afin d’identifier une situation de chute ou de
mouvement anormal."

Id = "1.2.3"

Seuils chute impact

«requirement»

Text = "Le système doit lire les accélérations selon les axes du MPU6050 afin d’
obtenir les données
nécessaires à l’analyse du mouvement."

Id = "1.2.1"

Lecture MPU6050

«requirement»

Text = "Le système doit
respecter la compatibilité des tensions, la masse
commune et l’absence de 5
V direct sur les GPIO de l’ ESP32-C3."

Id = "1.6"

REQ-06 Sécurité électrique

«requirement»

Text = "Le système doit
exploiter les données du
MPU6050 afin d’identifier
une chute libre, un impact ou un mouvement anormal
selon des seuils définis."

Id = "1.2"

REQ-02 Détection de chute

«requirement»

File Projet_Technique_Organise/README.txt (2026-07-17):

Projet Technique - Bracelet Intelligent

Description generale
--------------------
Cette archive regroupe les elements principaux du projet technique relatif a la conception d'un bracelet intelligent de surveillance cardiaque et de detection de chute. Elle contient les livrables academiques, les fichiers de conception electronique, les codes sources, les simulations, la modelisation SysML, la conception 3D CAD, l'application mobile Flutter, ainsi que les documents de support.

Organisation du projet
----------------------
01_Rapport/
    Contient le rapport academique du projet et les documents rediges lies a la presentation technique du travail.

02_Presentation/
    Contient la presentation du projet destinee a l'expose oral ou a la soutenance.

03_Code_Source/
    Contient les codes sources utilises dans le projet, notamment les programmes embarques ou les fichiers de developpement logiciel.

04_Simulation/
    Contient les fichiers de simulation utilises pour tester le fonctionnement du systeme avant realisation ou integration.

05_PCB_Eagle/
    Contient les fichiers Autodesk Eagle relatifs a la conception electronique de la carte, ainsi que les versions PDF du schema electrique et du PCB.
    Fichiers principaux :
        - Schema_Electrique.pdf
        - PCB_Carte_Principale.pdf
        - Schema_Electronique_Bracelet.sch
        - PCB_Carte_Bracelet.brd
        - Configuration_Eagle.epf
        - CAM_Job_Bracelet_02.job
        - CAM_Job_Bracelet_03.job
        - CAM_Job_Bracelet_04.job
        - CAM_Job_Bracelet_05.job
        - Projet_Eagle_Bracelet_02.pro
        - Projet_Eagle_Bracelet_03.pro
        - Projet_Eagle_Bracelet_04.pro
        - Projet_Eagle_Bracelet_05.pro

06_Documentation/
    Contient les documents techniques, notices, references ou ressources utiles a la comprehension du projet.

07_Archives_ou_Doublons/
    Contient les anciens fichiers, sauvegardes, versions intermediaires ou elements conserves comme archives afin de ne rien supprimer du projet initial.

08_Conception_3D_CAD/
    Contient les fichiers de conception mecanique et de modelisation 3D, notamment les elements CAD du boitier ou du bracelet.

09_Modelisation_SysML/
    Contient les fichiers de modelisation systeme, diagrammes SysML ou elements d'analyse fonctionnelle du projet.

10_Application_Mobile_Flutter/
    Contient le projet de l'application mobile Flutter associee au bracelet intelligent.
    Ce dossier regroupe principalement :
        - lib/
        - assets/ si present
        - android/
        - ios/ si present
        - web/ si present
        - pubspec.yaml
        - pubspec.lock
        - analysis_options.yaml

Fichiers principaux
-------------------
- Rapport du projet : disponible dans 01_Rapport/
- Presentation du projet : disponible dans 02_Presentation/
- Code source embarque : disponible dans 03_Code_Source/
- Simulation : disponible dans 04_Simulation/
- Schema electrique PDF : 05_PCB_Eagle/Schema_Electrique.pdf
- PCB PDF : 05_PCB_Eagle/PCB_Carte_Principale.pdf
- Schema Eagle : 05_PCB_Eagle/Schema_Electronique_Bracelet.sch
- Carte PCB Eagle : 05_PCB_Eagle/PCB_Carte_Bracelet.brd
- Conception 3D : disponible dans 08_Conception_3D_CAD/
- Modelisation SysML : disponible dans 09_Modelisation_SysML/
- Application mobile Flutter : disponible dans 10_Application_Mobile_Flutter/

Remarques
---------
- Les fichiers originaux du projet ont ete conserves dans leurs dossiers respectifs.
- Les fichiers de sauvegarde, versions intermediaires ou doublons sont regroupes dans 07_Archives_ou_Doublons/.
- Le schema electrique et le PCB sont regroupes dans le meme dossier 05_PCB_Eagle/ afin de garder ensemble tous les elements de conception electronique.
- L'application Flutter est placee dans 10_Application_Mobile_Flutter/ pour separer clairement la partie mobile du reste du projet technique.
- Les fichiers generes automatiquement par Flutter ou Gradle, comme build/, .dart_tool/ et .gradle/, ne sont pas necessaires pour la presentation academique et peuvent etre regeneres avec les commandes flutter pub get et flutter run.
- Les noms des dossiers sont numerotes pour faciliter la consultation et la presentation academique du projet.
- Aucun contenu interne des fichiers techniques n'a ete modifie.

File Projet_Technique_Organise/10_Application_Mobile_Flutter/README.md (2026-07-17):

# bracelet_app

A new Flutter project.

## Getting Started

This project is a starting point for a Flutter application.

A few resources to get you started if this is your first Flutter project:

- [Learn Flutter](https://docs.flutter.dev/get-started/learn-flutter)
- [Write your first Flutter app](https://docs.flutter.dev/get-started/codelab)
- [Flutter learning resources](https://docs.flutter.dev/reference/learning-resources)

For help getting started with Flutter development, view the
[online documentation](https://docs.flutter.dev/), which offers tutorials,
samples, guidance on mobile development, and a full API reference.

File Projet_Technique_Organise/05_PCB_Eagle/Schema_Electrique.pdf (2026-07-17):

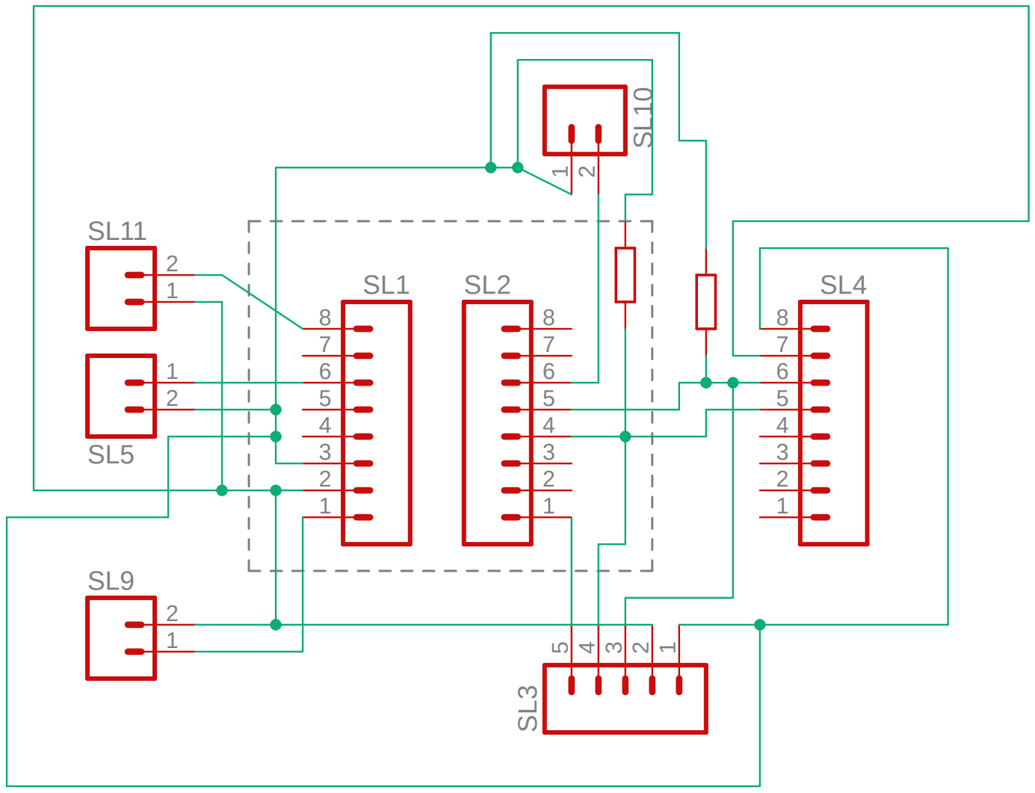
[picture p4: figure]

6/10/2026 11:25 AM f=2.00 C:\Users\Wael El Garrab\Downloads\Projet_Technique_Organise\05_PCB_Eagle\Schema_Electronique_Bracelet.sch (Sheet: 1/1)

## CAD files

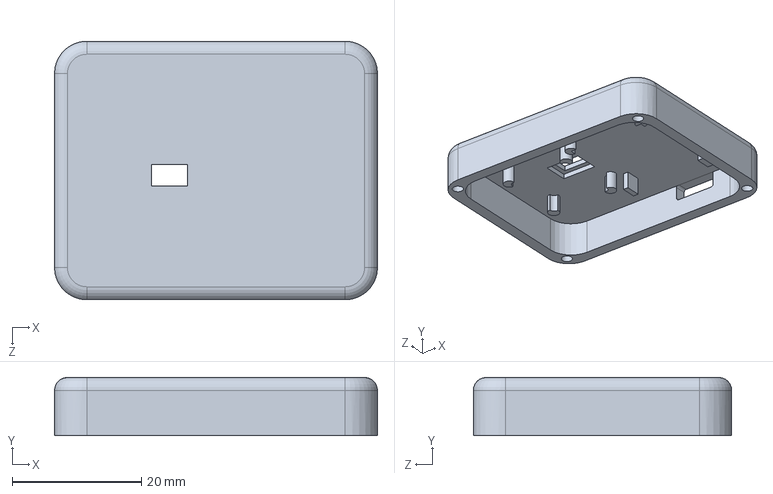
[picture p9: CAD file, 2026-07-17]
Projet_Technique_Organise/08_Conception_3D_CAD/Couvercle_Inferieur_Boitier.SLDPRT
50.0 x 9.00 x 40.0 mm

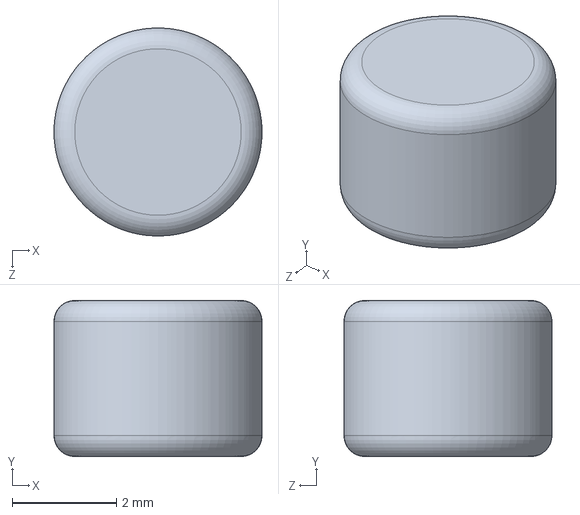
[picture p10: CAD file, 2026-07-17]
Projet_Technique_Organise/08_Conception_3D_CAD/Bouton_Commande.SLDPRT
4.00 x 3.00 x 4.00 mm

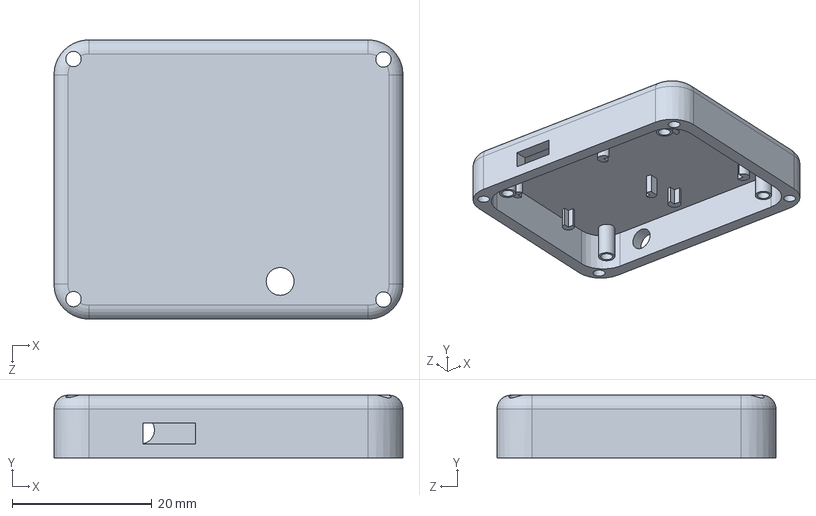
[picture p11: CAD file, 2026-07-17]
Projet_Technique_Organise/08_Conception_3D_CAD/Couvercle_Superieur_Boitier.SLDPRT
50.0 x 9.00 x 40.0 mm

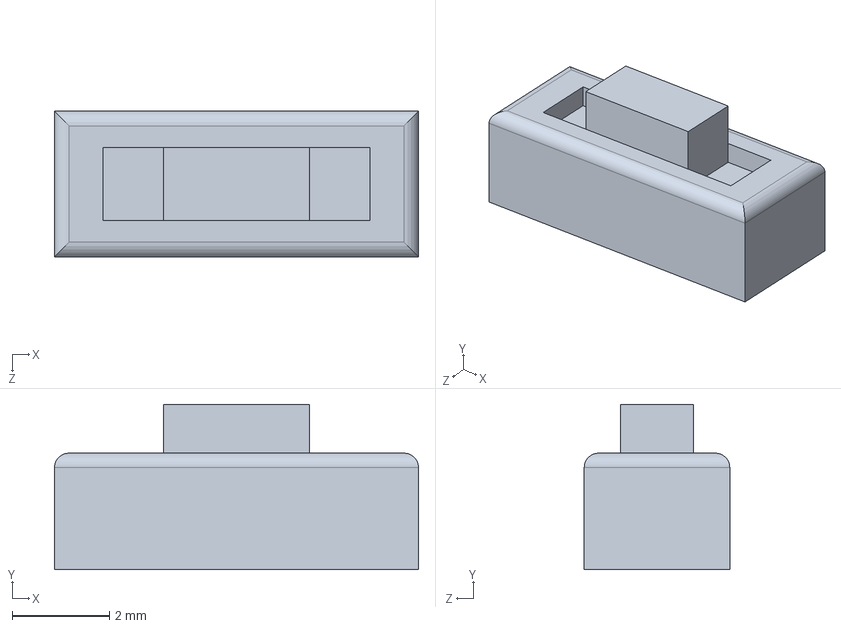
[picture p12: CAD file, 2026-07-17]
Projet_Technique_Organise/08_Conception_3D_CAD/Interrupteur_ON_OFF.SLDPRT
7.50 x 3.40 x 3.00 mm

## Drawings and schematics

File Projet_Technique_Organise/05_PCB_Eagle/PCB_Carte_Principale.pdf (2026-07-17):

SL3 SL9 | POWER_INPUT ON_OFF_SWITCH | MAX30102 ESP³²_RIGHT

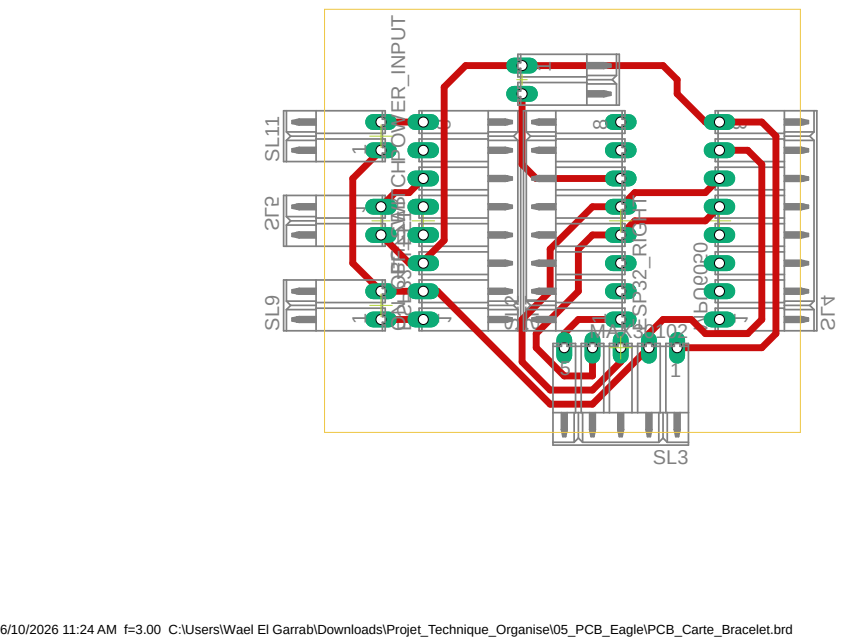
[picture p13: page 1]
6/10/2026 11:24 AM f=3.00 C:\Users\Wael El Garrab\Downloads\Projet_Technique_Organise\05_PCB_Eagle\PCB_Carte_Bracelet.brd ESP³²_LEFT; MPU⁶⁰⁵⁰ BUZZER

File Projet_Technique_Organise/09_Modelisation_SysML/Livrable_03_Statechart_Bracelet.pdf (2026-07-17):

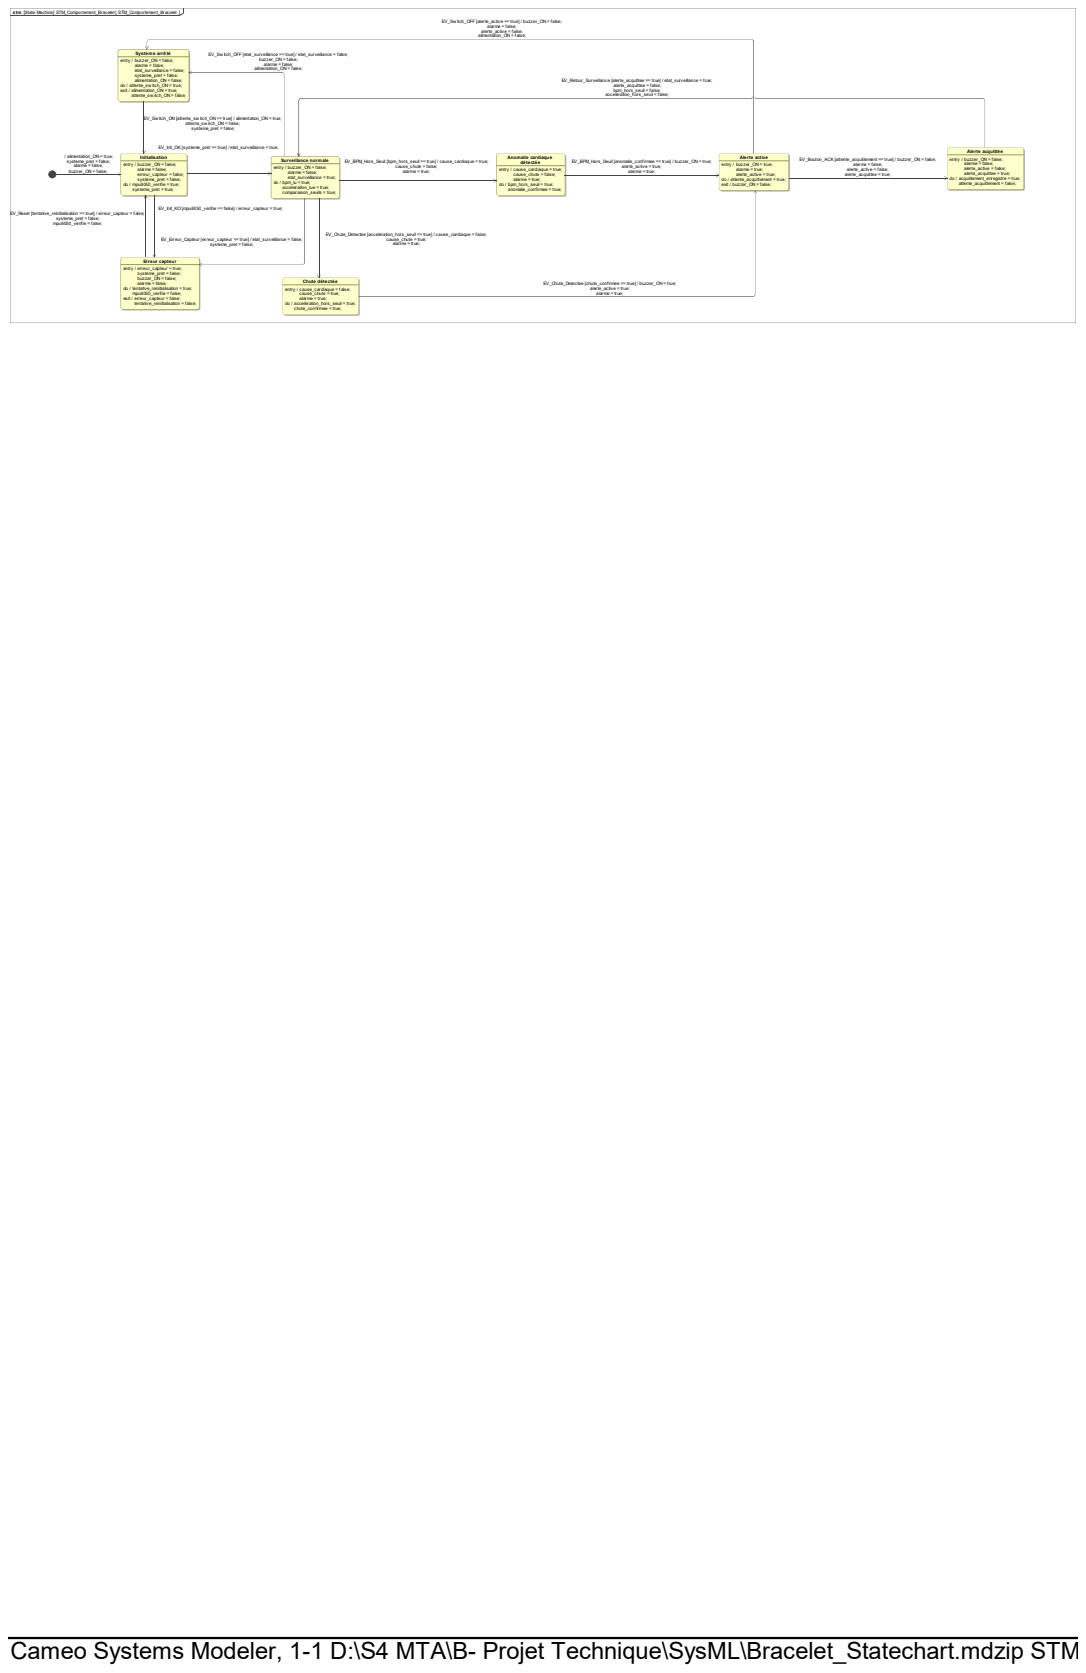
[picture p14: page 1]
erreur_capteur = false; tentative_reinitialisation = false;; exit /; tentative_reinitialisation = true; mpu6050_verifie = false;; erreur_capteur = true; systeme_pret = false; buzzer_ON = false; alarme = false;; entry /; Erreur capteur; acquittement_enregistre = true; attente_acquittement = false;; buzzer_ON = false; alarme = false; alerte_active = false; alerte_acquittee = true;; Alerte acquittée; acceleration_hors_seuil = true; chute_confirmee = true;; cause_cardiaque = false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

stm [State Machine] STM_Comportement_Bracelet [ STM_Comportement_Bracelet ]

Cameo Systems Modeler, 1-1 D:\S4 MTA\B- Projet Technique\SysML\Bracelet_Statechart.mdzip STM_Comportement_Bracelet May 9, 2026 5:21:02 PM

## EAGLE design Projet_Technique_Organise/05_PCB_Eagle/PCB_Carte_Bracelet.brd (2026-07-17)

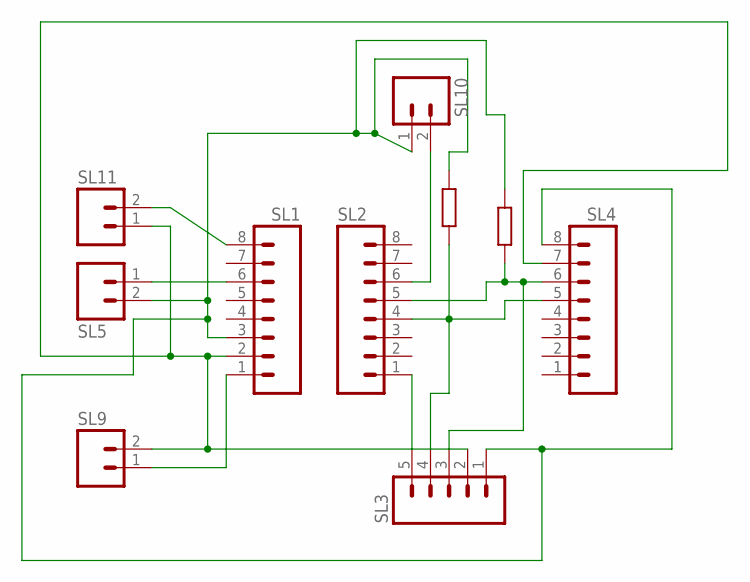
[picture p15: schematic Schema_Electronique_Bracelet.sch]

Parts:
SL1: ESP32_LEFT; 08PA
SL2: ESP32_RIGHT; 08PA
SL3: MAX30102; 05PA
SL4: MPU6050; 08PA
SL5: BUZZER; 02PA
SL9: ON_OFF_SWITCH; 02PA
SL10, SL11: POWER_INPUT; 02PA

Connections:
LED: SL1.2, SL3.2, SL4.7, SL9.2, SL11.1
unnamed: SL1.8, SL11.2
unnamed: SL1.1, SL9.1
unnamed: SL1.6, SL5.1
unnamed: SL1.3, SL3.1, SL4.8, SL5.2, SL10.1
unnamed: SL2.6, SL10.2
unnamed: SL2.1, SL3.5
NC_MPU_XCL: SL2.5, SL3.3, SL4.6
NC_MPU_XDA: SL2.4, SL3.4, SL4.5

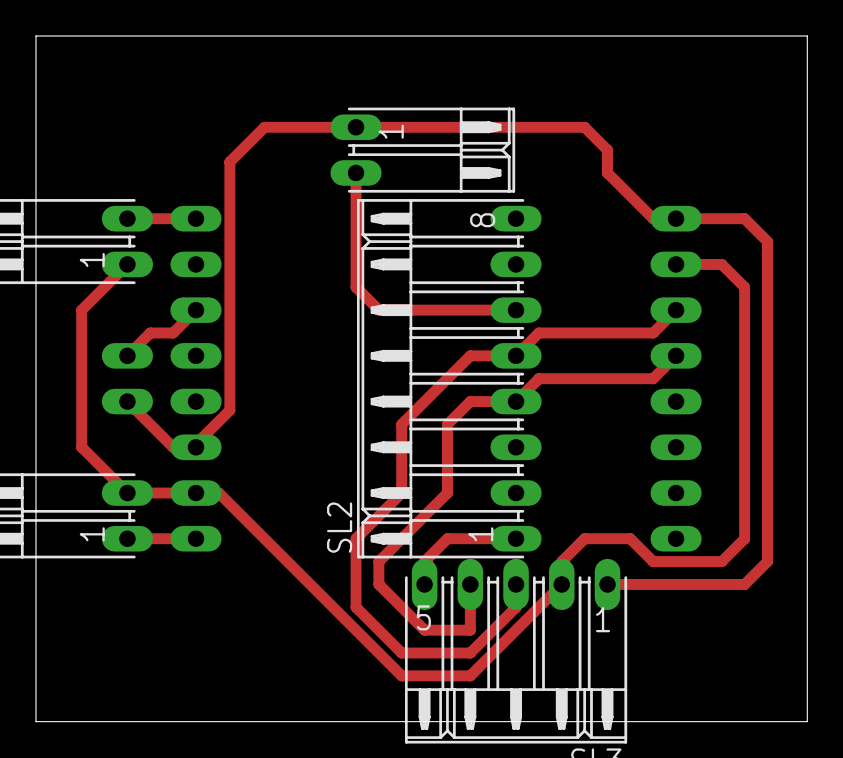
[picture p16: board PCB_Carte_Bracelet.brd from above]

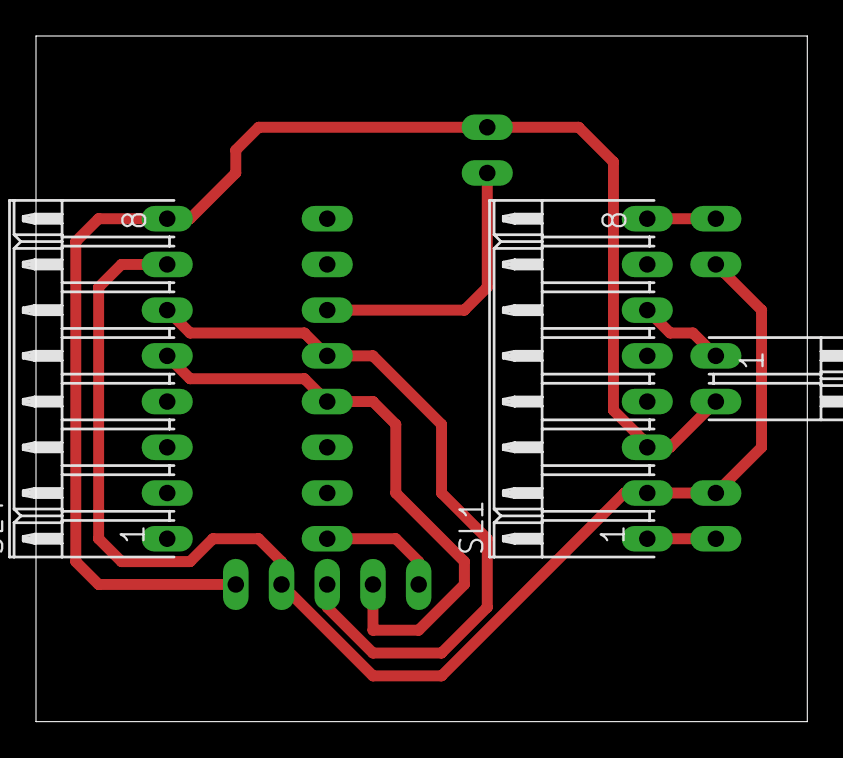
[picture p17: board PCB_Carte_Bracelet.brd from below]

Board: 2 copper layers, 42.9 x 38.1 mm, 8 parts (3 on the bottom side), 9 nets.

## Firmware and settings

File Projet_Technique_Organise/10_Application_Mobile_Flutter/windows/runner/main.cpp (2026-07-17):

#include <flutter/dart_project.h>
#include <flutter/flutter_view_controller.h>
#include <windows.h>

#include "flutter_window.h"
#include "utils.h"

int APIENTRY wWinMain(_In_ HINSTANCE instance, _In_opt_ HINSTANCE prev,
                      _In_ wchar_t *command_line, _In_ int show_command) {
  // Attach to console when present (e.g., 'flutter run') or create a
  // new console when running with a debugger.
  if (!::AttachConsole(ATTACH_PARENT_PROCESS) && ::IsDebuggerPresent()) {
    CreateAndAttachConsole();
  }

  // Initialize COM, so that it is available for use in the library and/or
  // plugins.
  ::CoInitializeEx(nullptr, COINIT_APARTMENTTHREADED);

  flutter::DartProject project(L"data");

  std::vector<std::string> command_line_arguments =
      GetCommandLineArguments();

  project.set_dart_entrypoint_arguments(std::move(command_line_arguments));

  FlutterWindow window(project);
  Win32Window::Point origin(10, 10);
  Win32Window::Size size(1280, 720);
  if (!window.Create(L"bracelet_app", origin, size)) {
    return EXIT_FAILURE;
  }
  window.SetQuitOnClose(true);

  ::MSG msg;
  while (::GetMessage(&msg, nullptr, 0, 0)) {
    ::TranslateMessage(&msg);
    ::DispatchMessage(&msg);
  }

  ::CoUninitialize();
  return EXIT_SUCCESS;
}

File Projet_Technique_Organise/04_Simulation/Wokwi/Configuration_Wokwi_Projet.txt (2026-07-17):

Downloaded from https://wokwi.com/projects/new/esp32-c3

Simulate this project on https://wokwi.com
